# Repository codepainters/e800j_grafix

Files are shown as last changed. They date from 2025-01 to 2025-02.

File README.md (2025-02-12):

# Elwro 800 Junior - GraFIX

The purpose of this tiny project is to fix a design flaw in the [Elwro 800 Junior](https://pl.wikipedia.org/wiki/Elwro_800_Junior) that causes visible graphical artifacts.

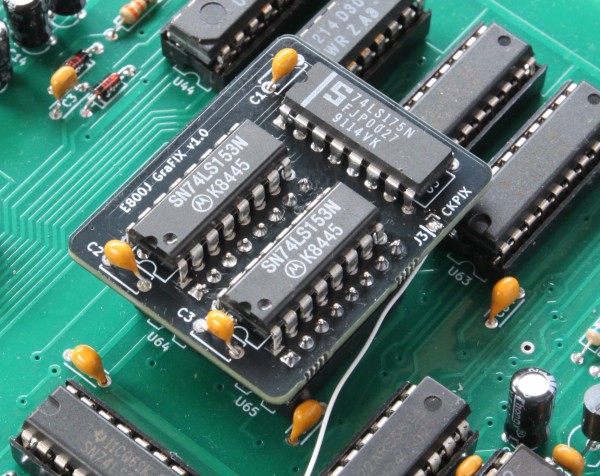
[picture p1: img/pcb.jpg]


In this repo:

* schematic/PCB project in KiCAD 8 format (in this very directory)
* PDF schematics - [color](grafix_sch.pdf) and [black&white](grafix_sch_bw.pdf)
* [interactive BOM](grafix_ibom.html) file (you have to download it and open locally)
* Gerber files (in a [jlcpcb](https://jlcpcb.com/)-compatible ZIP format):
  * [grafix.zip](gerbers/grafix.zip) - single PCB
  * [grafix_2x_panel.zip](gerbers/grafix_2x_panel.zip) - two PCBs panelized

## The problem & solution

The pictures below were taken before and after installing the `GraFIX` PCB. . In the first screenshot, green and blue artifacts are clearly visible around the green letters (other examples [here](img)). 

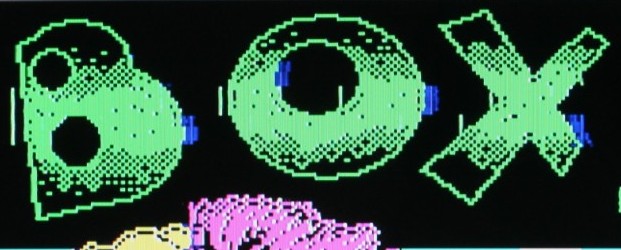
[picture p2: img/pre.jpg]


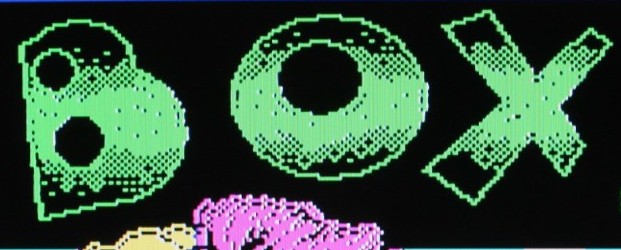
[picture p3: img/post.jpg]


Junior uses the same screen organization as the ZX Spectrum - every consecutive group of 8 pixels shares the same ink and paper color pair, the pixel value determines whether it is displayed in the ink or paper color. Junior employs two `74LS153` multiplexers for the color selection, this is a purely combinatorial circuit, unfortunately, leading to occasional short (~30ns) glitches visible as artifacts.

Fortunately, the multiplexer outputs remain stable around the rising edges of the `CKPIX` (pixel clock) signal. The `GraFIX` mod adds a 4-bit register (`74LS175`) at the multiplexer outputs, clocked by `CKPIX` (pixel clock) signal. This effectively latches a stable color value for each pixel, eliminating the glitches.

## Assembling

When soldering the PCB, follow this order: pin headers under `U2`, then `U2` itself, followed by pin headers under `U1`, and finally `U1`. Soldering all the pin headers first makes it difficult to solder pins 9 to 16 of `U2` due to the small gap between the inner pin headers (been there, done that). See below:

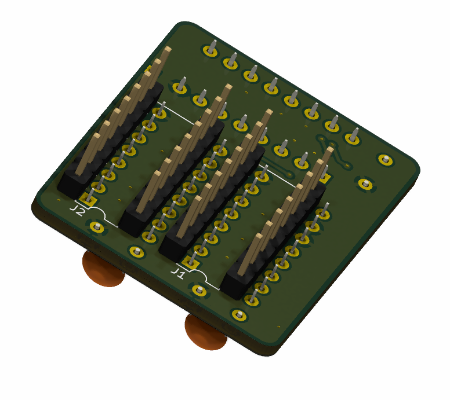
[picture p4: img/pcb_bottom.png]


Then you have to unsolder `74LS153` multiplexers and replace them with `DIL-16` sockets, now you can insert `GraFIX` PCB into the sockets. The last step is to connect `J3` header on the `GraFIX` board to `CKPIX` signal on the Junior PCB with a short piece of wire. The best place to do it is a via close to `R38`, marked with red `X`. That's it!

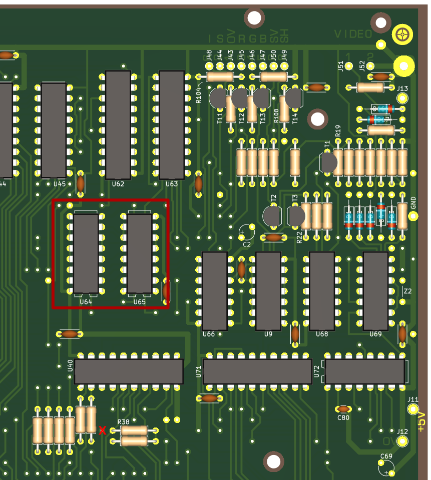
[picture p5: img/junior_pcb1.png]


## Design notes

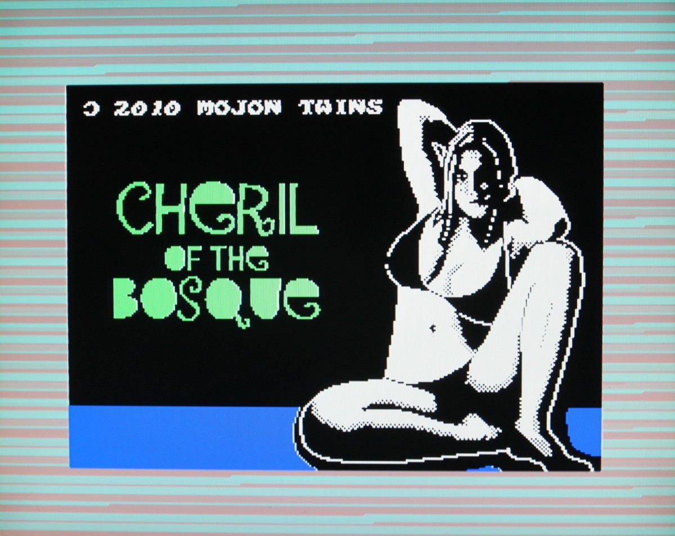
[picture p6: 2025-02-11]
img/screen_3_ok.jpg

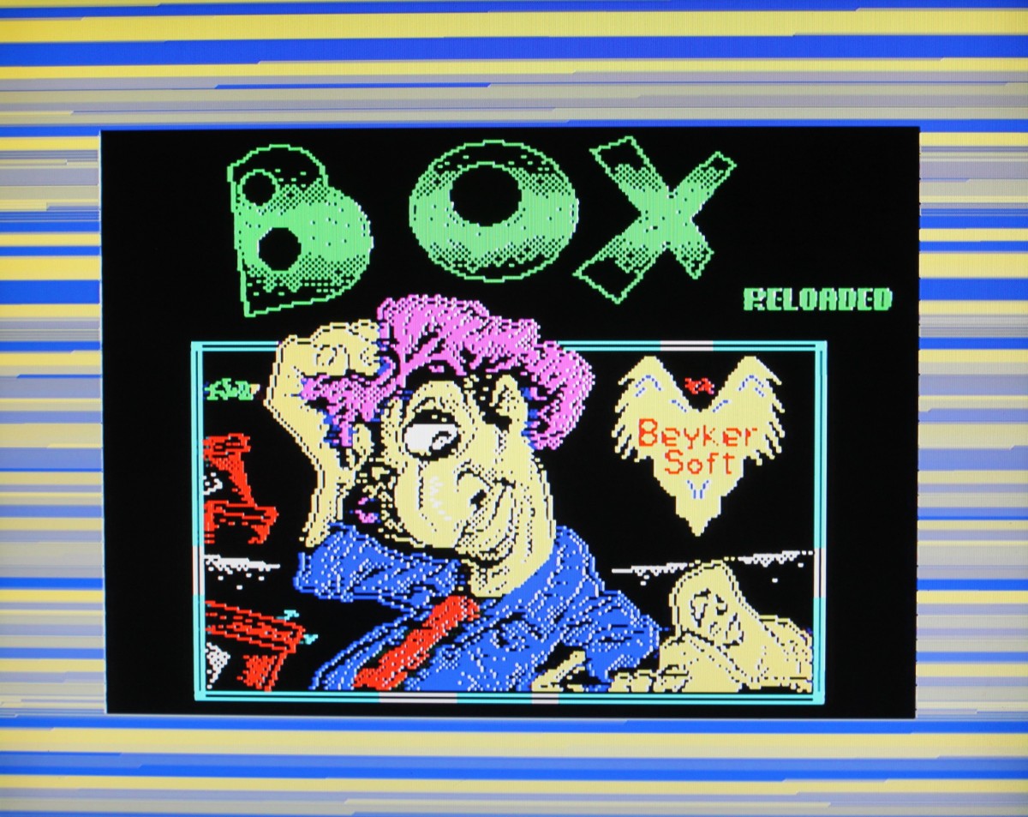
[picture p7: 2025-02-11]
img/screen_2_ok.jpg

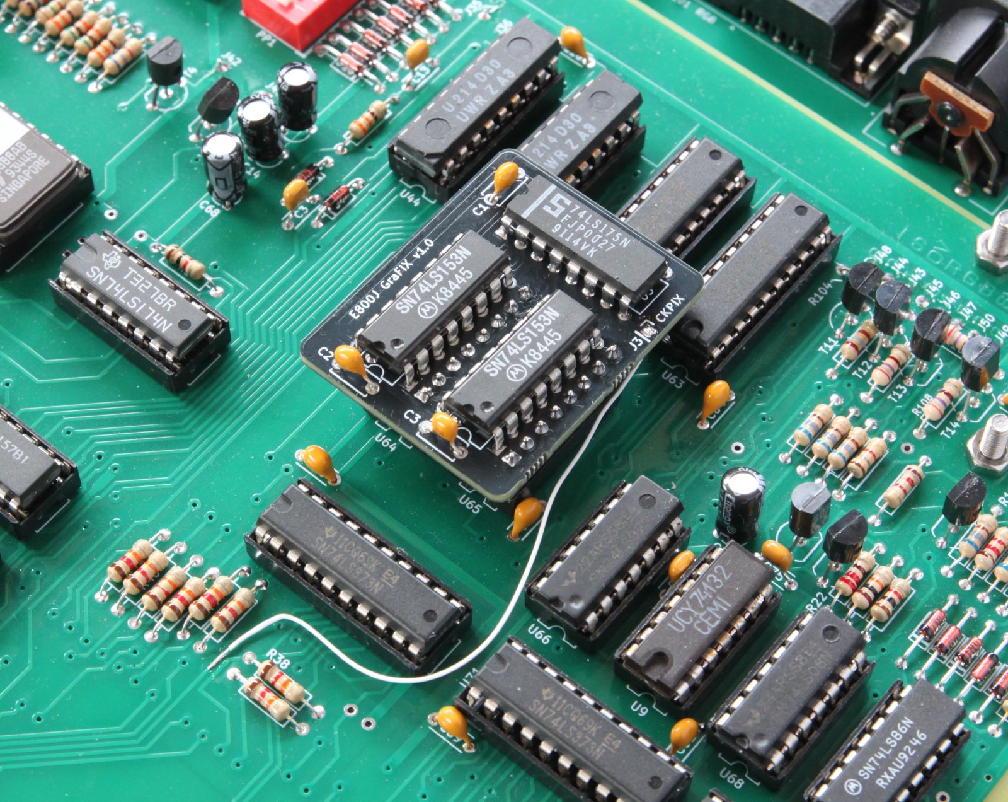
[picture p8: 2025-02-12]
img/pcb_big.jpg

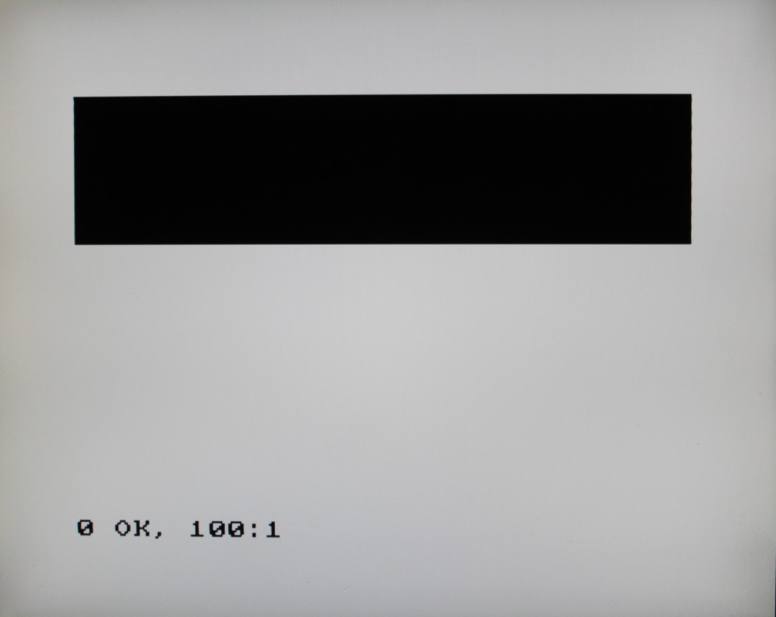
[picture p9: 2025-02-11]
img/screen_1_ok.jpg

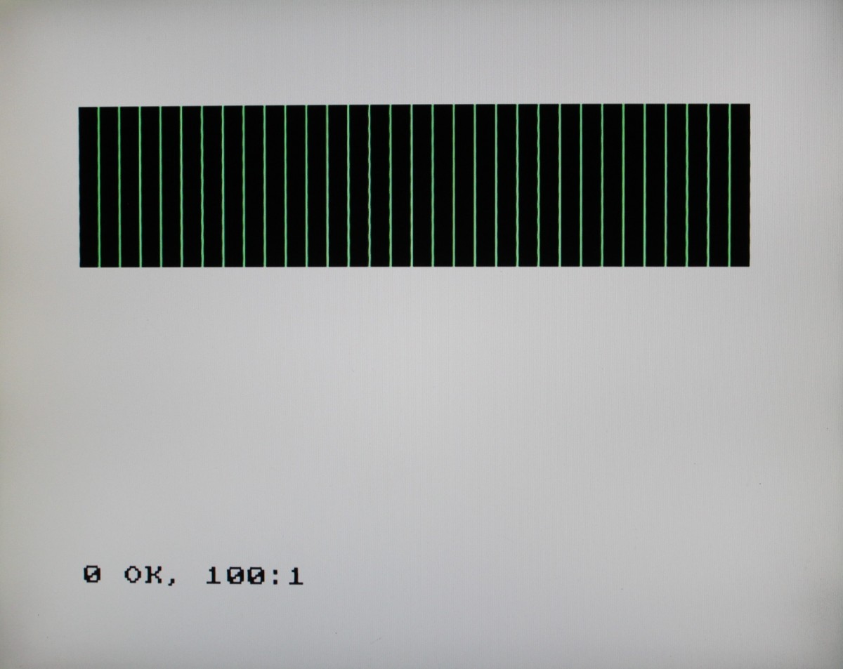
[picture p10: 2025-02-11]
img/screen_1_bad.jpg

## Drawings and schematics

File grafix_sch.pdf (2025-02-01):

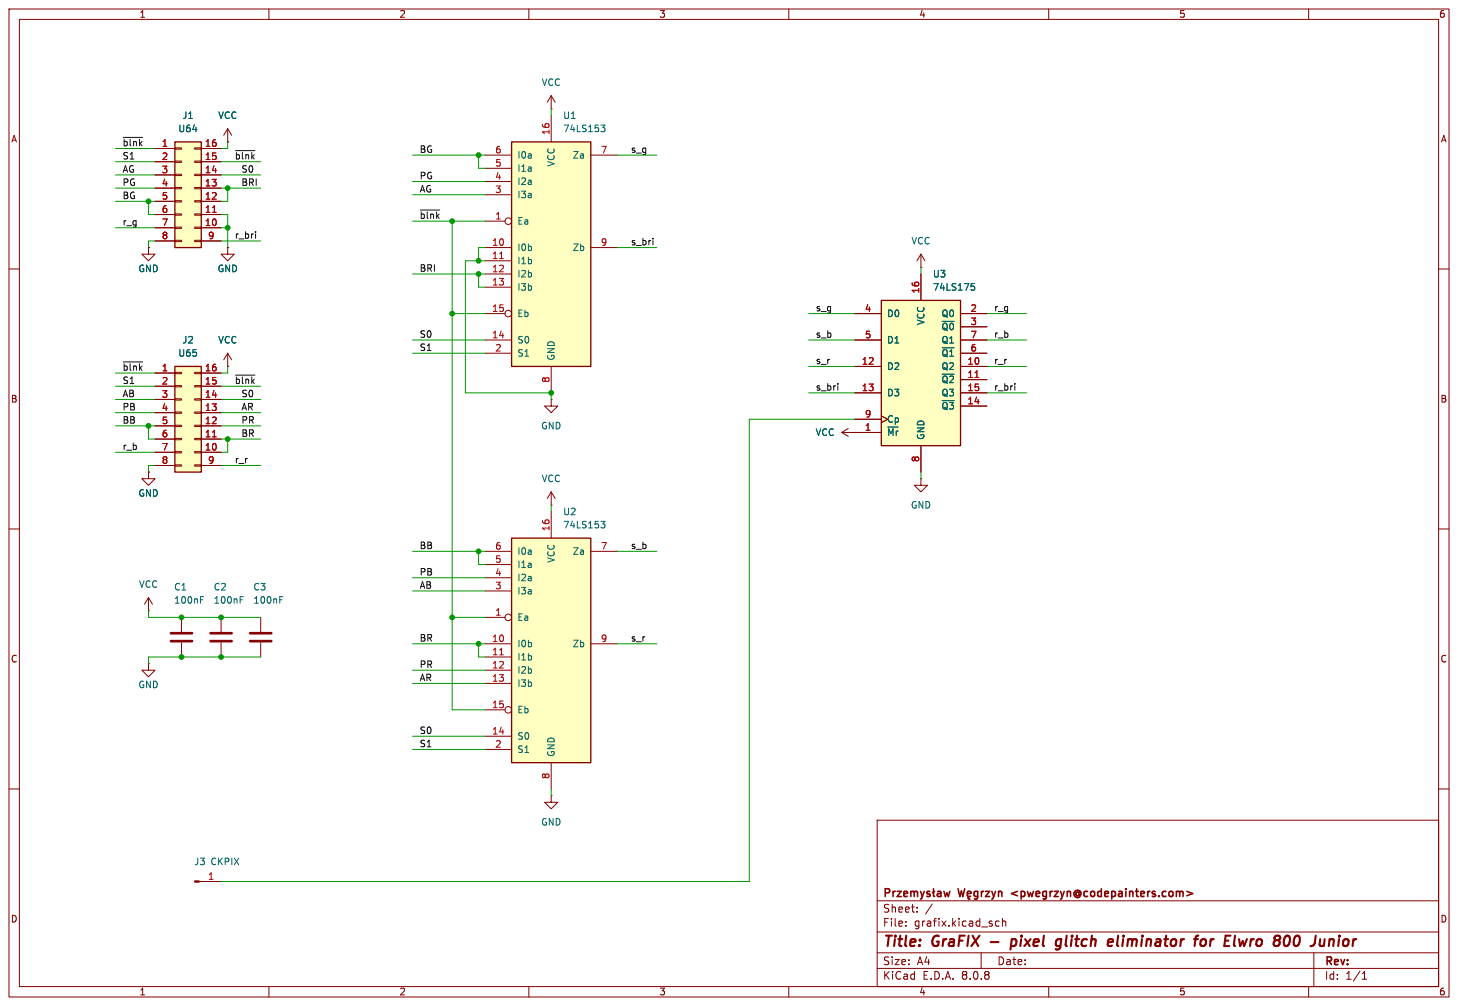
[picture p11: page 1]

Id: 1/1 Title: GraFIX - pixel glitch eliminator for Elwro 800 Junior File: grafix.kicad_sch Sheet: / þÿPrzemysBaw þÿWgrzyn <pwegrzyn@codepainters.com>

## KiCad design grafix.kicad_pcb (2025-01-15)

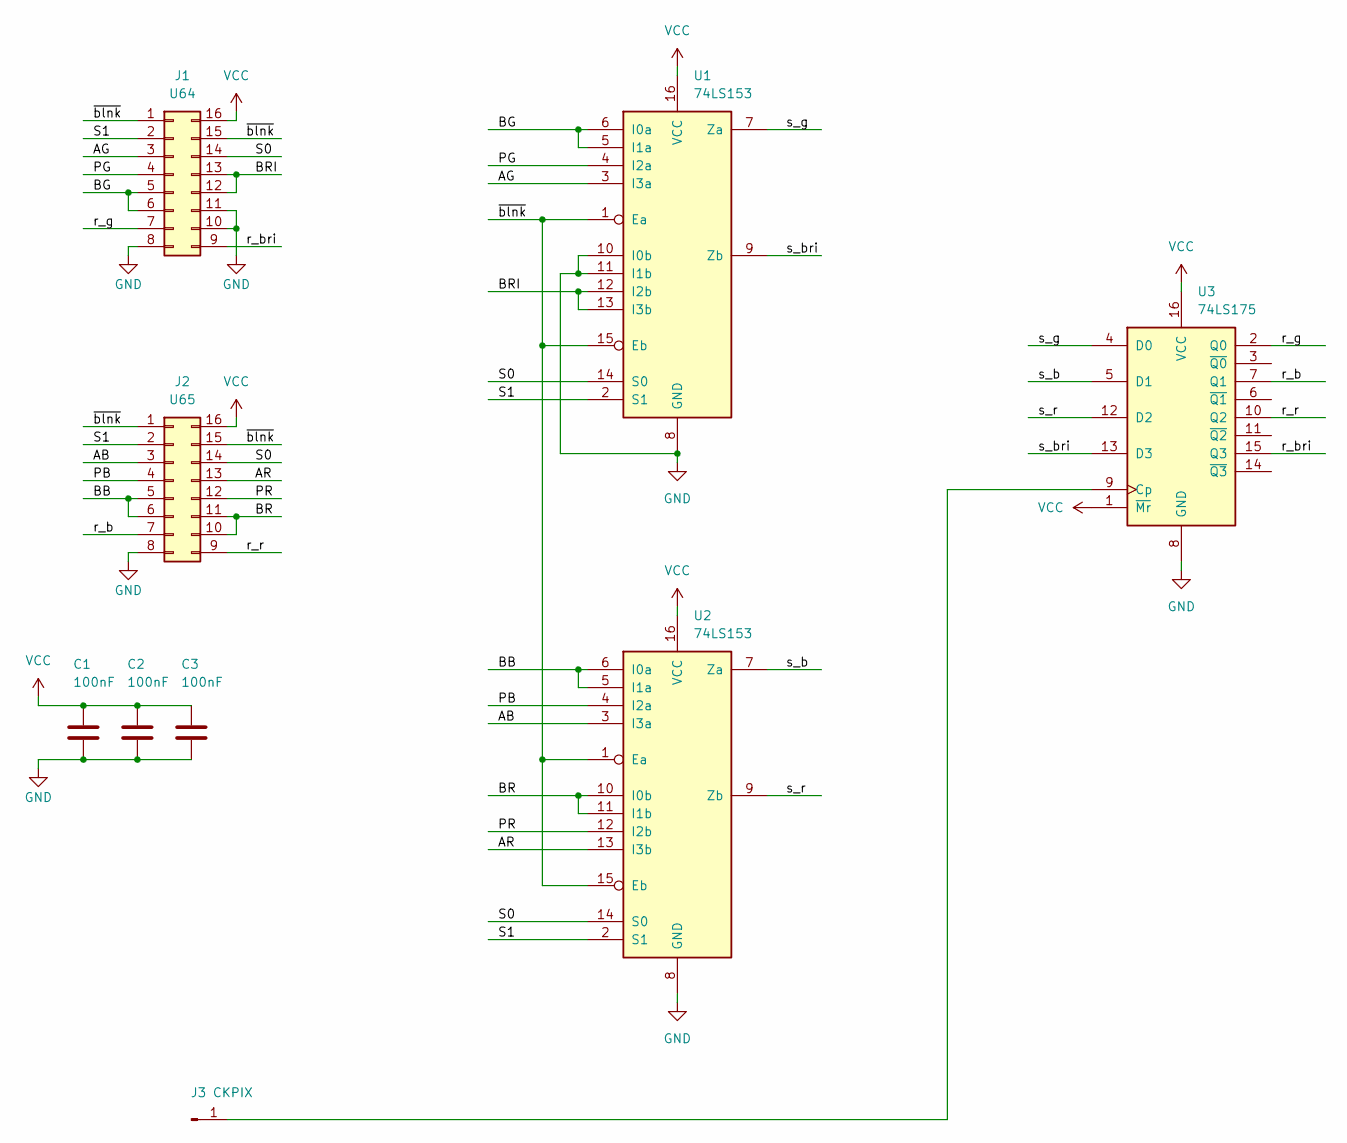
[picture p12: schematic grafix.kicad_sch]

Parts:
C1, C2, C3: 100nF; C_Disc_D5.0mm_W2.5mm_P5.00mm
J1: U64; DIP16_pins
J2: U65; DIP16_pins
J3: CKPIX; PinHeader_1x01_P2.00mm_Vertical
U1, U2: 74LS153; DIP-16_W7.62mm
U3: 74LS175; DIP-16_W7.62mm

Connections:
/AB: J2.3, U2.3 (I3a)
/AG: J1.3, U1.3 (I3a)
/AR: J2.13, U2.13 (I3b)
/BB: J2.5, J2.6, U2.5 (I1a), U2.6 (I0a)
/BG: J1.5, J1.6, U1.5 (I1a), U1.6 (I0a)
/BR: J2.10, J2.11, U2.10 (I0b), U2.11 (I1b)
/BRI: J1.12, J1.13, U1.12 (I2b), U1.13 (I3b)
/PB: J2.4, U2.4 (I2a)
/PG: J1.4, U1.4 (I2a)
/PR: J2.12, U2.12 (I2b)
/S0: J1.14, J2.14, U1.14 (S0), U2.14 (S0)
/S1: J1.2, J2.2, U1.2 (S1), U2.2 (S1)
/r_b: J2.7, U3.7 (Q1)
/r_bri: J1.9, U3.15 (Q3)
/r_g: J1.7, U3.2 (Q0)
/r_r: J2.9, U3.10 (Q2)
/s_b: U2.7 (Za), U3.5 (D1)
/s_bri: U1.9 (Zb), U3.13 (D3)
/s_g: U1.7 (Za), U3.4 (D0)
/s_r: U2.9 (Zb), U3.12 (D2)
/~blnk: J1.1, J1.15, J2.1, J2.15, U1.1 (Ea), U1.15 (Eb), U2.1 (Ea), U2.15 (Eb)
GND: C1.2, C2.2, C3.2, J1.8, J1.10, J1.11, J2.8, U1.8 (GND), U1.10 (I0b), U1.11 (I1b), U2.8 (GND), U3.8 (GND)
unnamed: J3.1, U3.9 (Cp)
VCC: C1.1, C2.1, C3.1, J1.16, J2.16, U1.16 (VCC), U2.16 (VCC), U3.1 (~Mr), U3.16 (VCC)

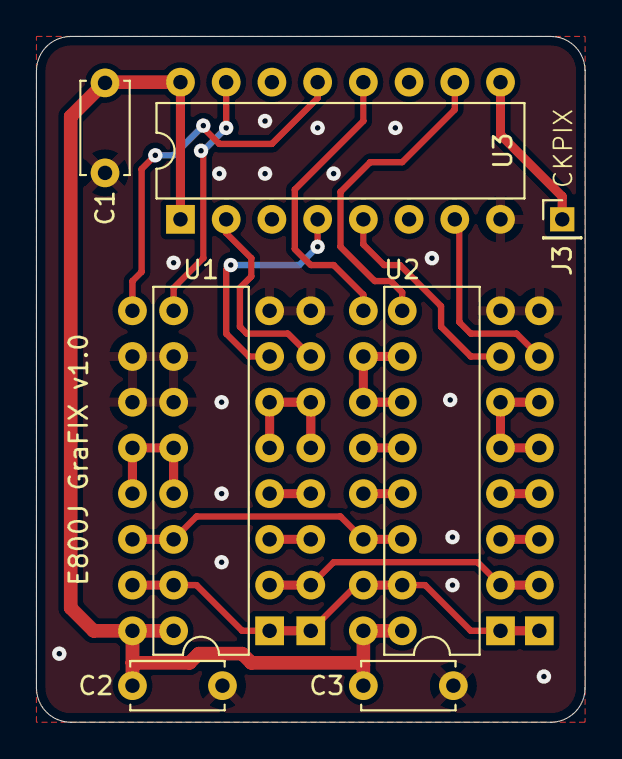
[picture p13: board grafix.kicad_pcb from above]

Board: 2 copper layers, 30.5 x 38.1 mm, 9 parts (0 on the bottom side), 24 nets.

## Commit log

2025-01-15 Initial version.
    [grafix.kicad_pcb, grafix.kicad_sch]
2025-01-15 Minor tweaks
    [grafix.kicad_pcb]
2025-02-01 Added interactive BOM.
    Closes #3
2025-02-01 Minor schematic fix
    [grafix.kicad_sch]
2025-02-01 Schematic as PDF
    Closes #2
2025-02-01 Added gerbers for regular and 2x planel versions
